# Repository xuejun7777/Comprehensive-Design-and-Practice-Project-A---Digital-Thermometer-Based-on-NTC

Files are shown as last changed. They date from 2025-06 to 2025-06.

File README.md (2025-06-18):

# NTC数字温度计综合设计项目

## 项目简介

基于STM32G030微控制器和NTC热敏电阻的数字温度计系统，包含完整的硬件设计、软件开发和PCB制作。

## 系统架构

### 硬件组成
- **MCU**: STM32G030 (ARM Cortex-M0+)
- **传感器**: NTC热敏电阻 (10kΩ@25°C, B=3950K)
- **显示**: 4位7段数码管
- **接口**: USB Type-C + UART

### 软件功能
- 12位ADC温度采集
- Steinhart-Hart方程温度转换
- 动态数码管显示
- 串口数据输出
- 开机学号显示

## 核心特性

- **通信**: 115200bps UART

## 项目结构

```
├── g030_adc_uart/          # 主程序代码
├── g030_display/           # 显示驱动
├── NTC/                    # 硬件设计V1
├── NTC2/                   # 硬件设计V2
├── final_submit/           # 最终提交文件
└── *.pdf                   # 实验报告文档
```

## 关键算法

### 温度转换公式
```c
// Steinhart-Hart方程
T = 1/((ln(Rt/R0)/B) + (1/T0)) - 273.15
```

### 自然对数实现
```c
// 泰勒级数展开避免math.h依赖
double tsp_ln(double a) {
    // 15阶泰勒级数计算
}
```

## 编译环境

- **IDE**: Keil MDK-ARM V5.39.0.0
- **编译器**: ArmClang V6.21
- **代码大小**: ~8KB Flash, ~2KB RAM

## 功能验证

✅ 温度测量精度  
✅ 数码管显示  
✅ 串口通信  
✅ 学号显示  
✅ 异常检测  
✅ PCB硬件  

## 应用场景

- 温度监测系统
- 实验室测温设备  
- 工业过程控制
- 教学实验平台

---

*本项目展示了完整的嵌入式系统开发流程，从硬件设计到软件实现的工程实践。*

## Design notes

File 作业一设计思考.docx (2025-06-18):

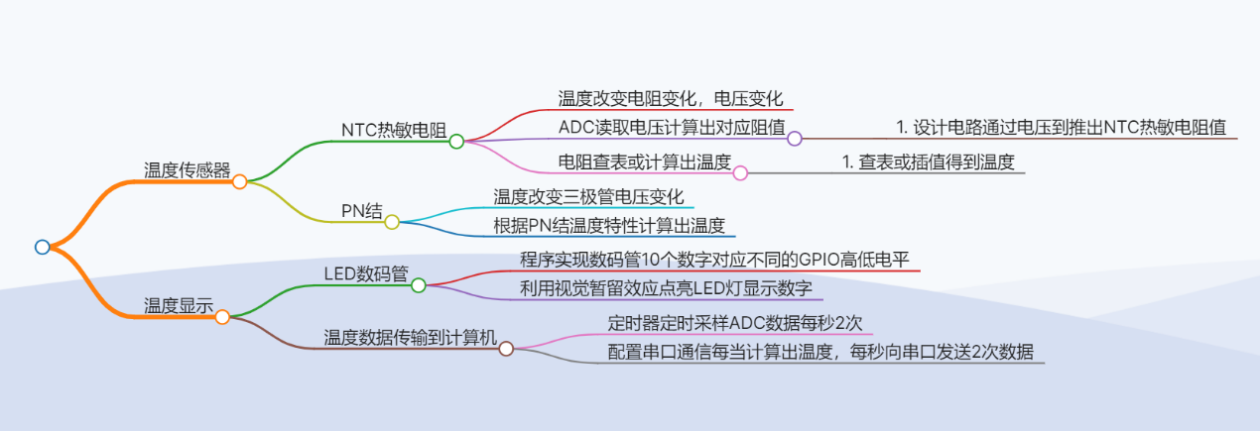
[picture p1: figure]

配置串口将温度通过串口传输到计算机

LED数码管显示

使用定时器定时每秒进行两次ADC的采样

单片机ADC采样的数字信号算出NTC电阻或PN结电压，计算出当前温度

NTC或PN结温度传感器，温度引起电阻或电压变化

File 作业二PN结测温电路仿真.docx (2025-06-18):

# 作业二PN结测温电路仿真

1、设计一个恒流源（可用器件：电阻、运放），可提供100uA恒定电流；

使用电阻和运算放大器的虚短虚断特性组成恒流源，简化示意图如下：

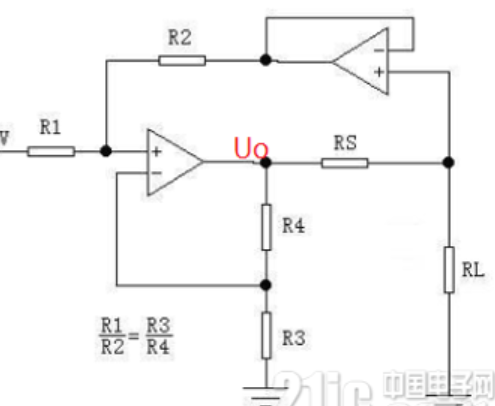
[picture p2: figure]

V*R2/R1=I*RS

单5V电源供电时，选择R1为10k Ω，R2为2k Ω，RS电阻值为10kΩ即可得到100uA恒定电流。

2、设计电路，减小反向比例电路中R1对测量精度的影响；

使用运算放大器组成电压缓冲器，由于虚断，反相输入端不会分流电流源的电流。

3、整个电路采用单5V电源供电；

使用到的所有运算放大器电源正端接5v电源，负端接地。

4、运放同相输入端的偏置电压以电阻网络的形式提供，请计算电阻阻值；

运放同相输入端需要偏置电压，使用两个电阻对5v电源分压，观察PN结温度特性可知需要偏置电压为588mv，计算出需用两个电阻（对应图中R5和R7）分别为11kΩ和1.6kΩ，即可将温度0~100℃对应到电压0.5v~3.5v。

5、运放增益、偏置如何调整？

调整运放的增益和偏置只需要调整相应的电阻网络，调整运放增益可以调节反相输入端所接电阻和反馈电阻（对应图中R10和R6）的阻值，或者接入可变电阻，调节可变电阻；调整偏置调整第4问中两个电阻（对应图中R5和R7）阻值或者接入可变电阻，调节可变电阻即可。

电路图如下：

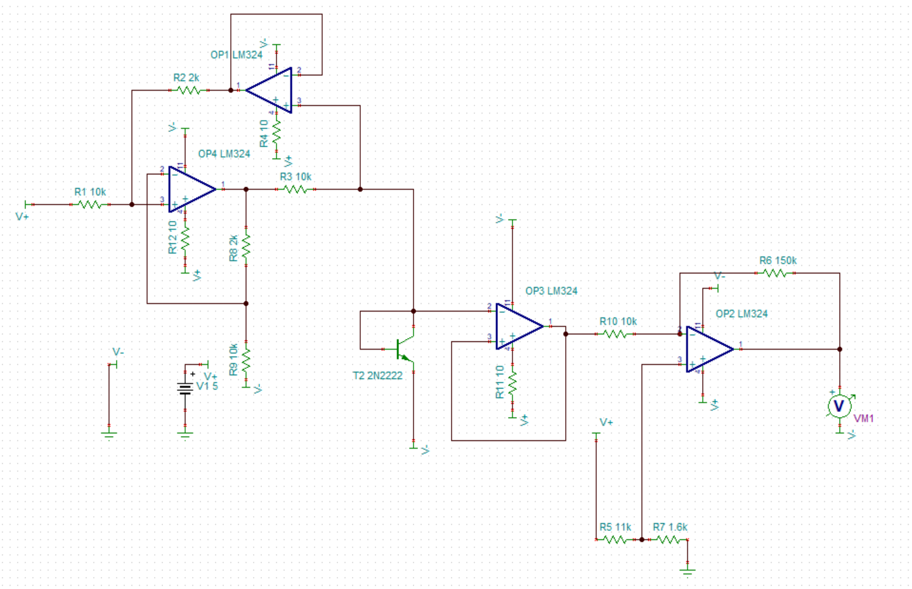
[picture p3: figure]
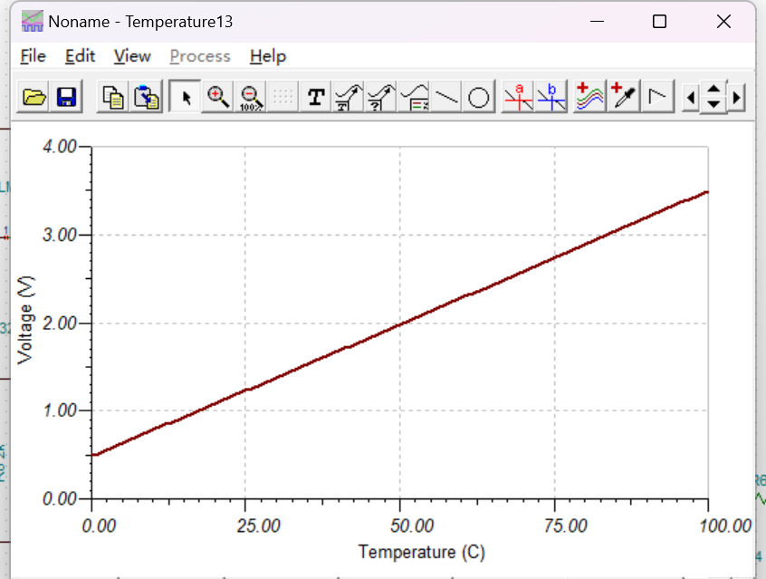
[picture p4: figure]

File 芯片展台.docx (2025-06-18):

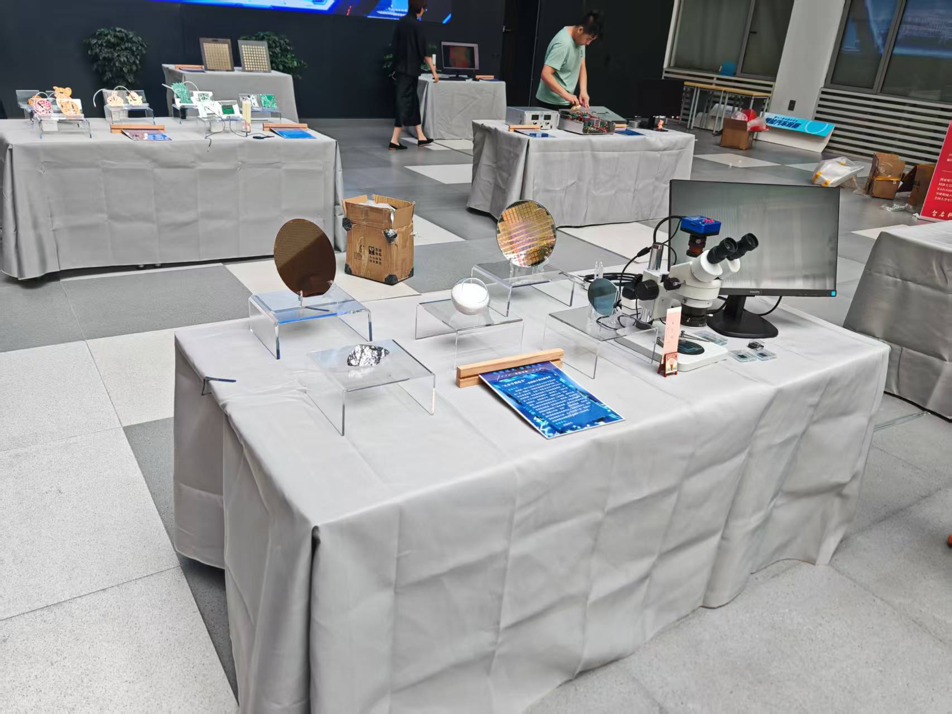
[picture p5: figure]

芯片展台

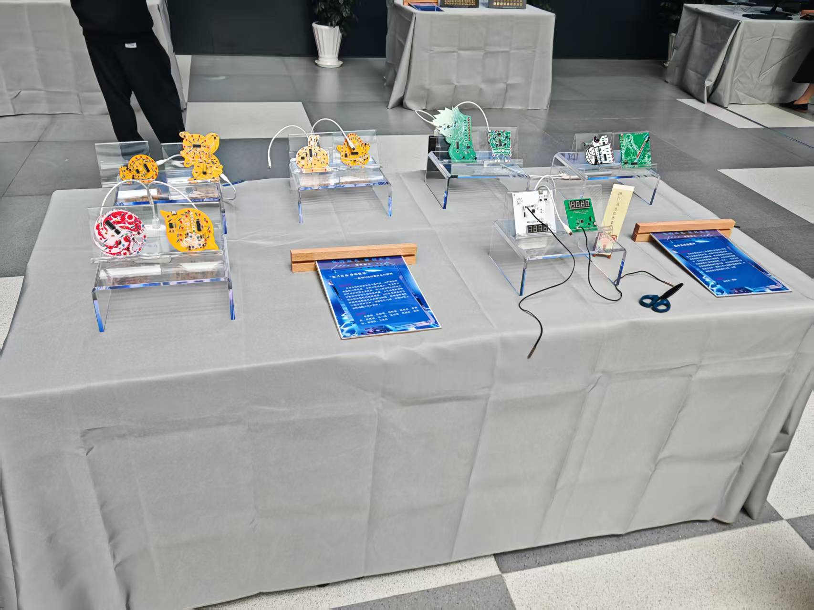
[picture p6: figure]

流水灯展台

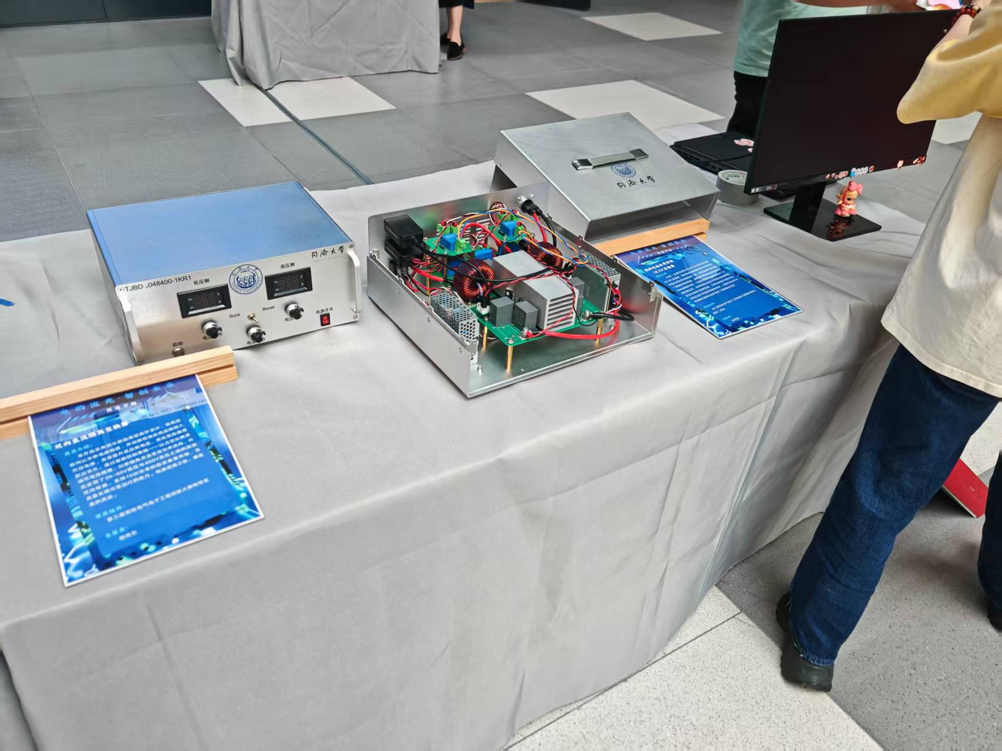
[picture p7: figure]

DC/DC变换器展台

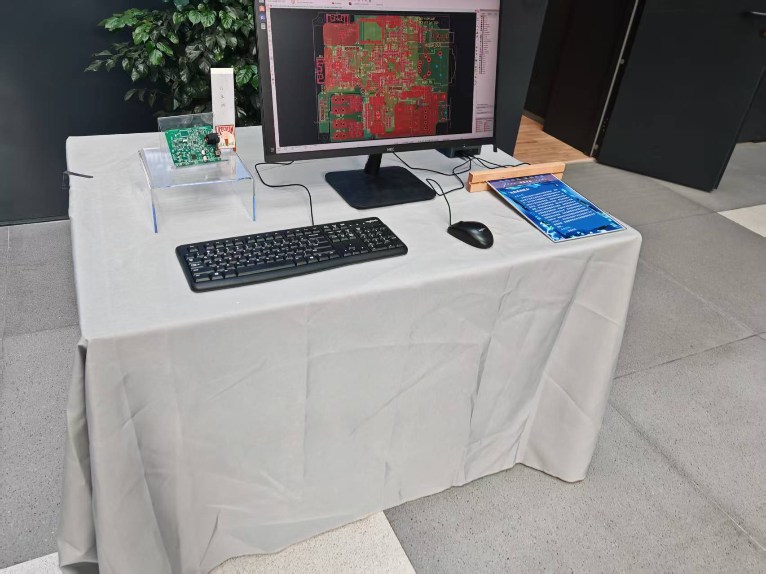
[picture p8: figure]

PCB电路板展台

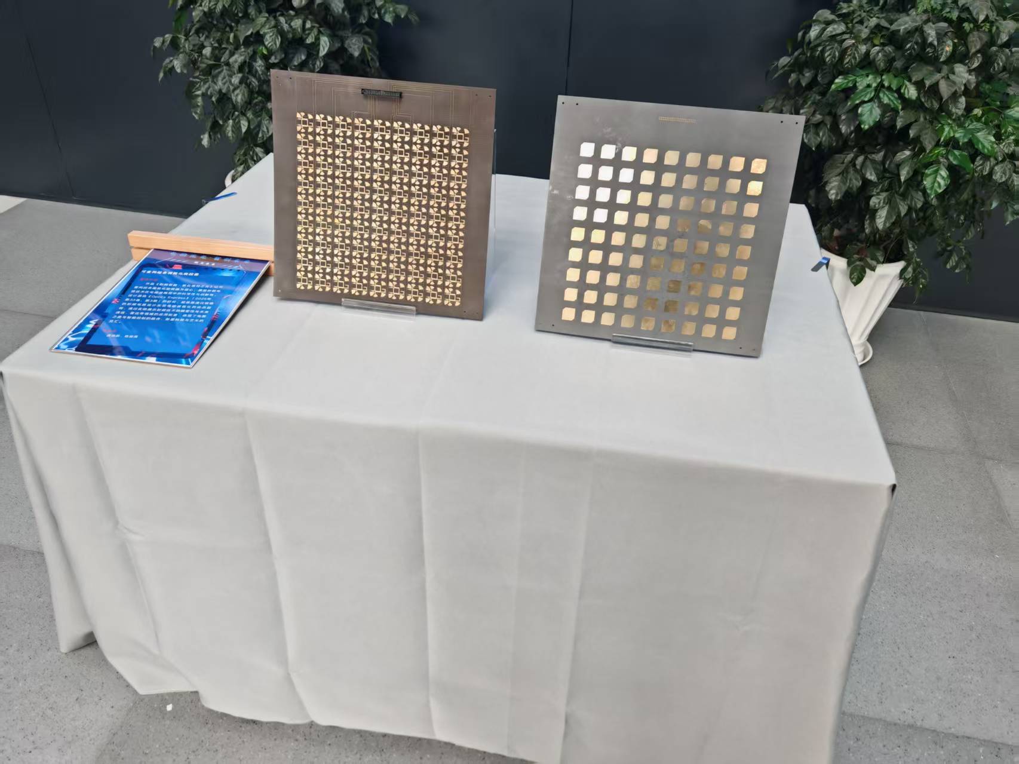
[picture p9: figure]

旋控器展台

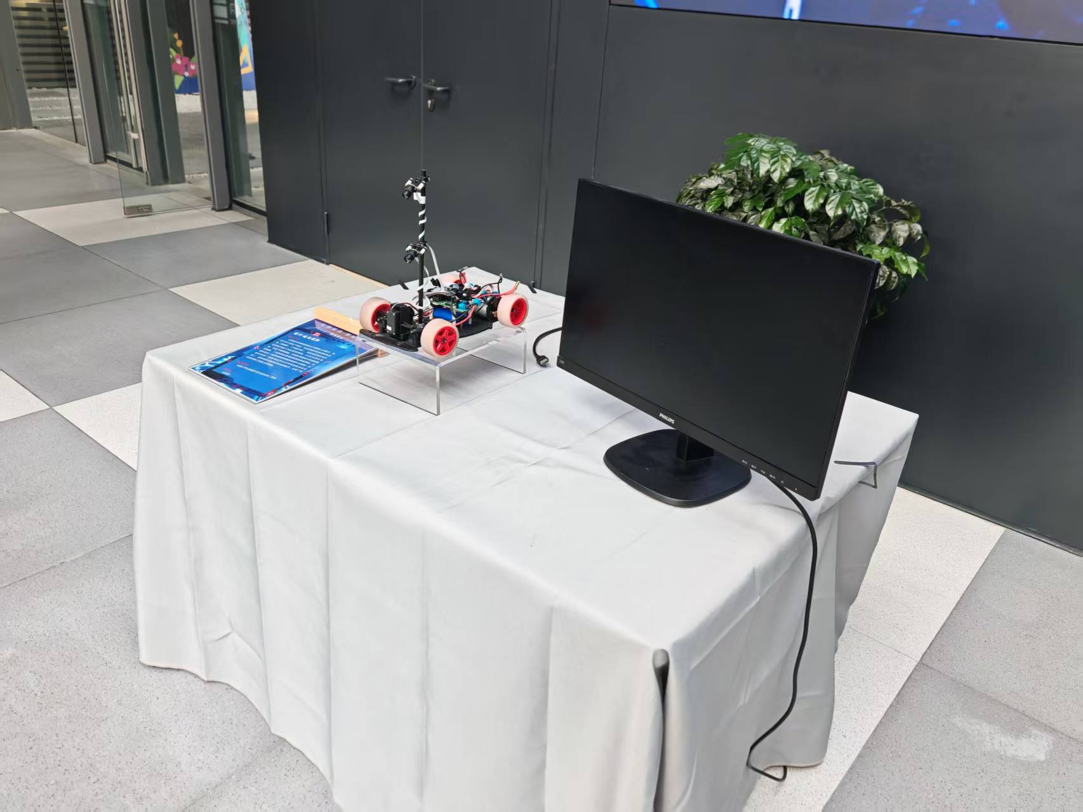
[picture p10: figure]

智能小车展台

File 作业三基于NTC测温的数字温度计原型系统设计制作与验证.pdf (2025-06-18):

## 基于 NTC 测温的数字温度计原型系统设计制作与验

## 证实验报告

引言

本实验的目的是设计一个使用 LED 数码管作为显示器件的数字温度计，通过测量 NTC 电阻 值来获取温度数据。实验中使用了 minisys G030 最小系统板，并通过 ADC 外设进行数据采 集，采集到的 NTC 热敏电阻的分压通过一系列换算得到温度数据并使用 LED 数码管显示。

## 电路设计

使用元器件 minisys G030、排针、排母、9013 三极管、数码管、330Ω、1KΩ、10KΩ 的电阻 等器件，根据要求，我们设计了以下电路：
1. NTC 电阻与一个 10KΩ 固定电阻构成 3.3V 的参考电压的分压网络，并使用单片机 ADC(PA0 管脚)测量中点电压；
2. 整个电路采用 minisys G030 最小系统板上提供的单 5V 电源供电；
3. 数码管八个笔端使用 minisys G030 上 PB0-7 串联 330Ω电阻直接驱动，4 个公共阴极使 用三极管扩流，并使用 minisys G030 上 PD0-3 驱动，三极管基极串一个 1kΩ电阻限流； 电路图如下：
图中的 STM32G030 及周边电路由 minisys G030 提供，原型电路需要连接 minisys、数码管 以及三极管、电阻等元器件。

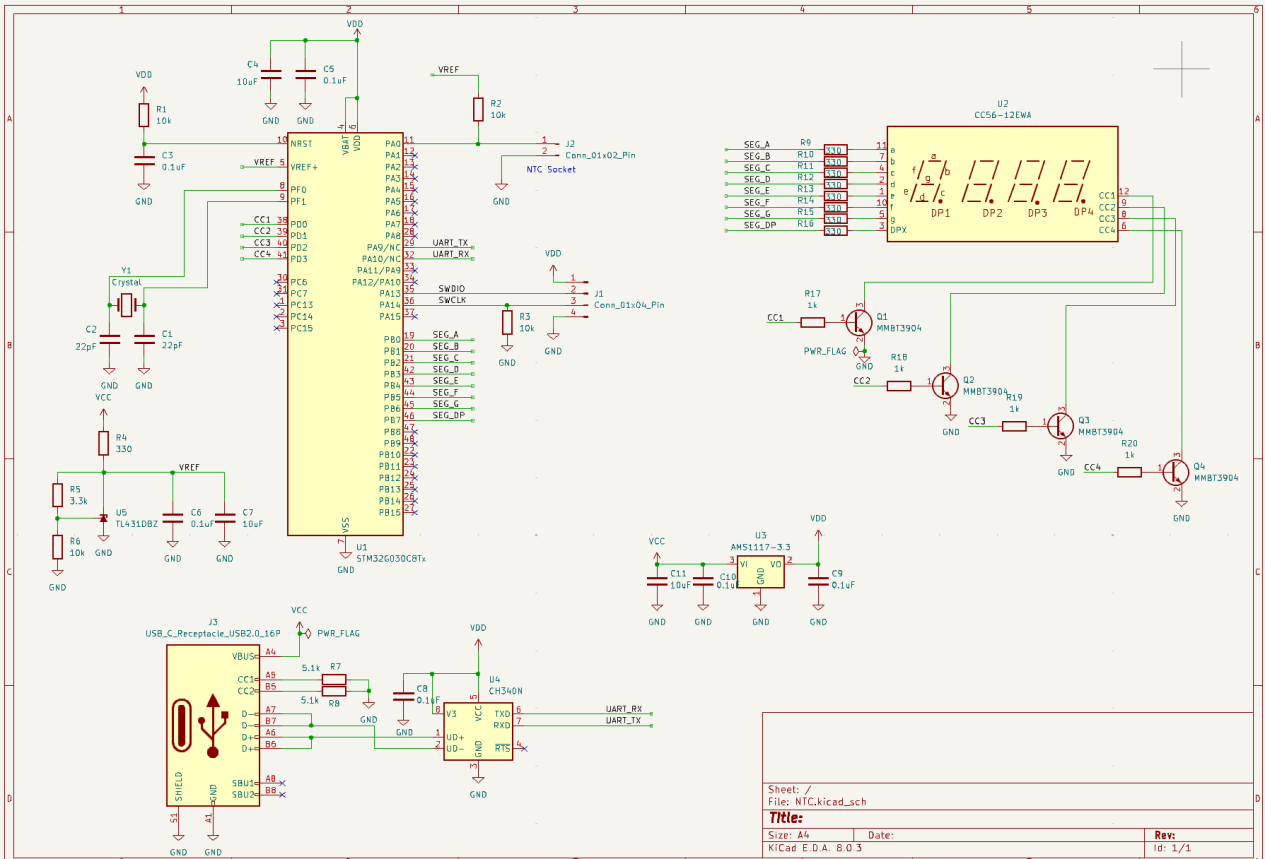
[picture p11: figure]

## 程序编写

根据要求编写单片机程序，实现了下功能：
1. LED 数码管动态扫描显示
按照时刻按照一定规则选择使能四个数码管的其中一个，数码管在 8 个笔端写入数字对 应的电平，下一个时刻使用另一个数码管并写入相应数字对应的电平即实现了动态扫描 显示数字，这样就可以尽可能少占用单片机管脚。
2. 每秒 2 次 ADC 数据采集
配置定时器 TIM3，要求 2Hz 频率采样 PA0 脚的电压，在 STM32CubeMX 中配置时钟树 64MHz，PSR 为 511，ARR 为 62499，并设置 ADC 采样转换的触发源是 TIM3 定时器溢 出就能实现每秒 2 次 ADC 数据采集。
3. 电阻值测量计算
NTC 热敏电阻与 10kΩ电阻对 3.3v 参考电压进行分压，根据 DC 采集的电压可以倒推出

NTC 电阻值，公式为R =

10000
3.3
v

-1

。

4. 根据 NTC 的温度-电阻函数，计算测得的温度数据，并显示在 LED 数码管上。
由于 STM32G030 不支持计算复杂运算，无法直接使用公式通过温度-电阻函数计算出温 度（不能进行对数计算），可以使用查表的方式根据表格中温度-电阻的对应关系，对于 表格中没有的阻值对应的温度可以将温度-阻值近似为线性函数进行线性插值（在实际 程序中直接定义使用 ADC-温度对应的表格数组进行一系列插值运算），得到温度值传给 处理数码管的函数，即可将温度显示在数码管上。

## 测试结果

实物图片：

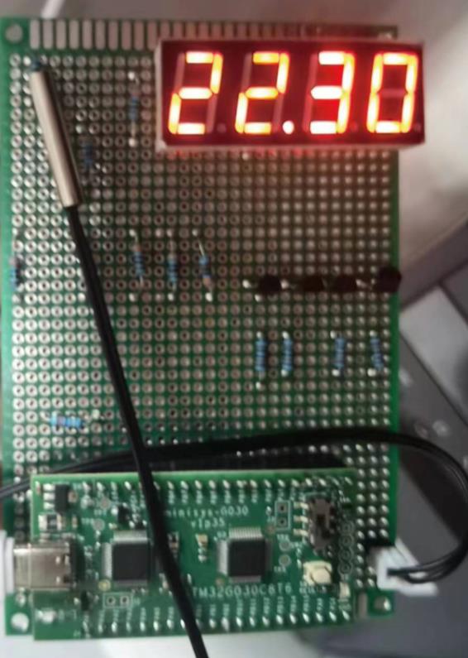
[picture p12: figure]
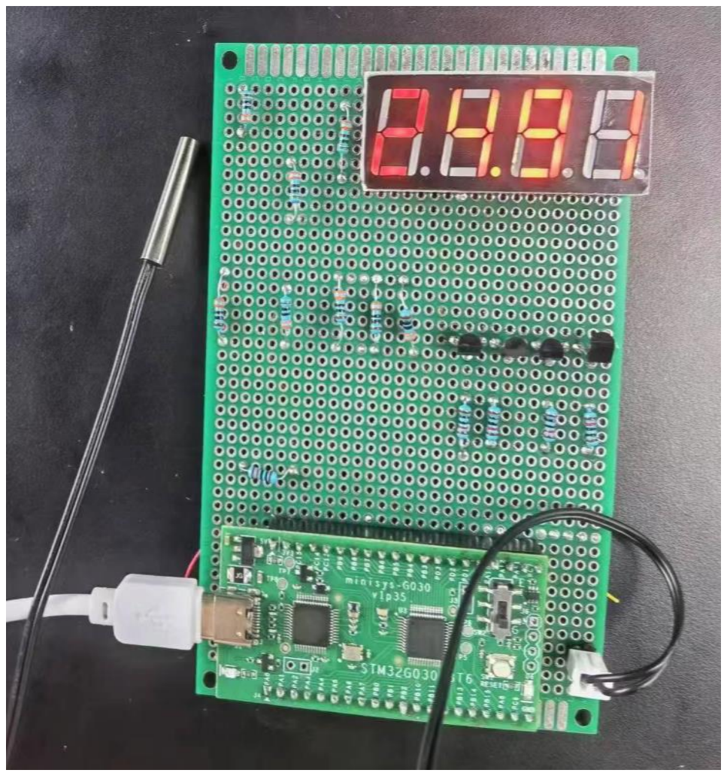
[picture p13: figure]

测试图片
图片展示升温过程：

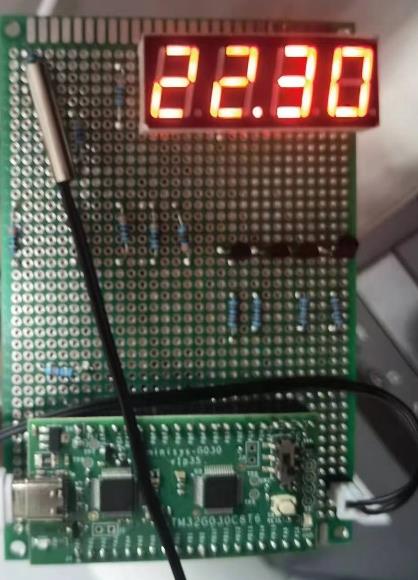
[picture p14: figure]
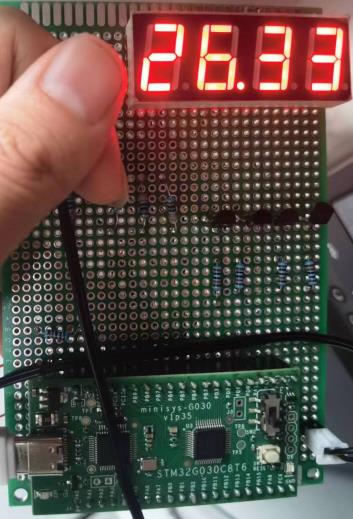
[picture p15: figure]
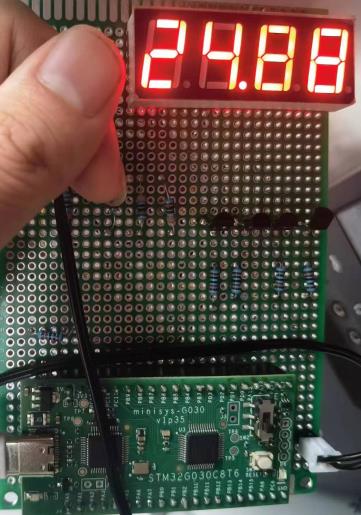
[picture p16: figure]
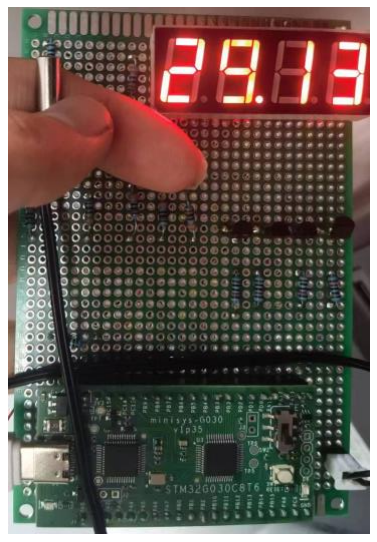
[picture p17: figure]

测试说明原型系统能够完成温度的计算然后用数码管显示温度数据，并且符合温度变化趋 势。
总结

通过本次实验，我们成功地设计并焊接了一个使用 LED 数码管作为显示器件的数字温度计 的原型系统。我们通过 ADC 采样分到的电压推算 NTC 电阻值和温度数据，并在 LED 数码管 上进行显示，设计并焊接的原型系统能够完成温度的计算，用数码管显示温度数据，并且符 合温度变化趋势。

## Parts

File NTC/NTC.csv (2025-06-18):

编号 | 位号 | 封装 | 数量 | 名称 | 供应商编号
1 | C6,C10,C9,C3,C8,C5 | C_0805_2012Metric_Pad1.18x1.45mm_HandSolder | 6 | 0.1uF
2 | R6,R1,R3,R2 | R_0805_2012Metric_Pad1.20x1.40mm_HandSolder | 4 | 10k
3 | C4,C11,C7 | C_0805_2012Metric_Pad1.18x1.45mm_HandSolder | 3 | 10uF
4 | J1 | PinHeader_1x04_P2.54mm_Vertical | 1 | Conn_01x04_Pin
5 | Q3,Q2,Q1,Q4 | SOT-23 | 4 | MMBT3904
6 | R15,R12,R9,R14,R13,R4,R16,R10,R11 | R_0805_2012Metric_Pad1.20x1.40mm_HandSolder | 9 | 330
7 | R17,R20,R18,R19 | R_0805_2012Metric_Pad1.20x1.40mm_HandSolder | 4 | 1k
8 | U2 | CA56-12EWA | 1 | CC56-12EWA
9 | R5 | R_0805_2012Metric_Pad1.20x1.40mm_HandSolder | 1 | 3.3k
10 | R7,R8 | R_0805_2012Metric_Pad1.20x1.40mm_HandSolder | 2 | 5.1k
11 | U4 | SOIC-8_3.9x4.9mm_P1.27mm | 1 | CH340N
12 | J3 | USB_C_Receptacle_HCTL_HC-TYPE-C-16P-01A | 1 | USB_C_Receptacle_USB2.0_16P
13 | U3 | SOT-223-3_TabPin2 | 1 | AMS1117-3.3
14 | C1,C2 | C_0805_2012Metric_Pad1.18x1.45mm_HandSolder | 2 | 22pF
15 | J2 | JST_XH_B2B-XH-A_1x02_P2.50mm_Vertical | 1 | Conn_01x02_Pin
16 | U1 | LQFP-48_7x7mm_P0.5mm | 1 | STM32G030C8Tx
17 | U5 | SOT-23 | 1 | TL431DBZ
18 | Y1 | Crystal_SMD_5032-2Pin_5.0x3.2mm | 1 | Crystal

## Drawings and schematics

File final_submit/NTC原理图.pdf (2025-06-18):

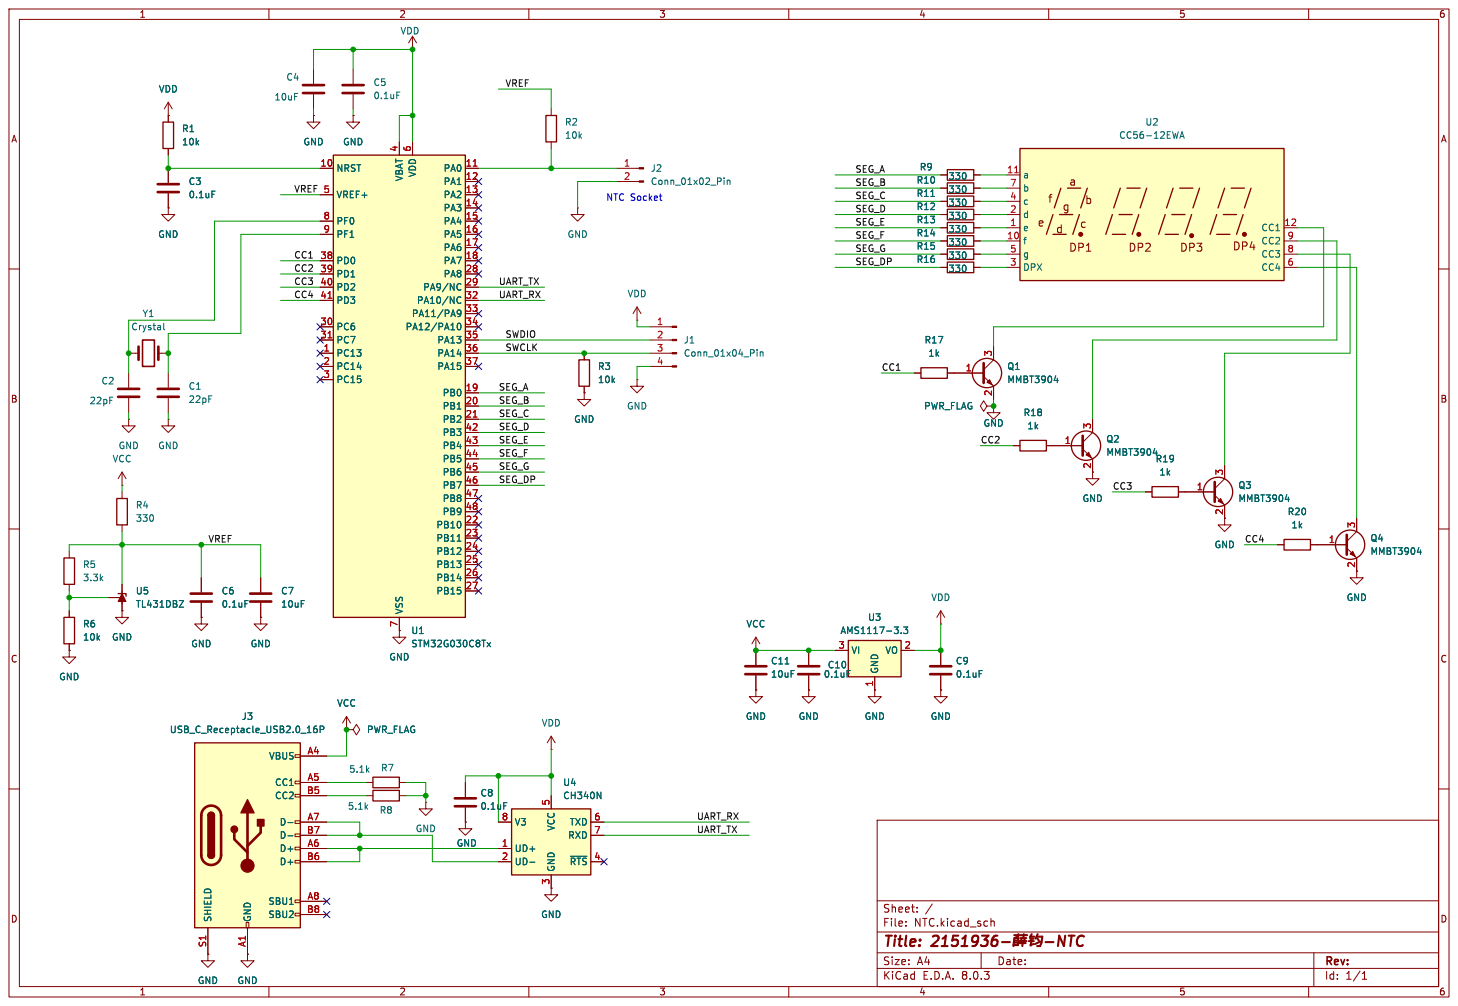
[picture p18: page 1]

File: NTC.kicad_sch Sheet: / GND

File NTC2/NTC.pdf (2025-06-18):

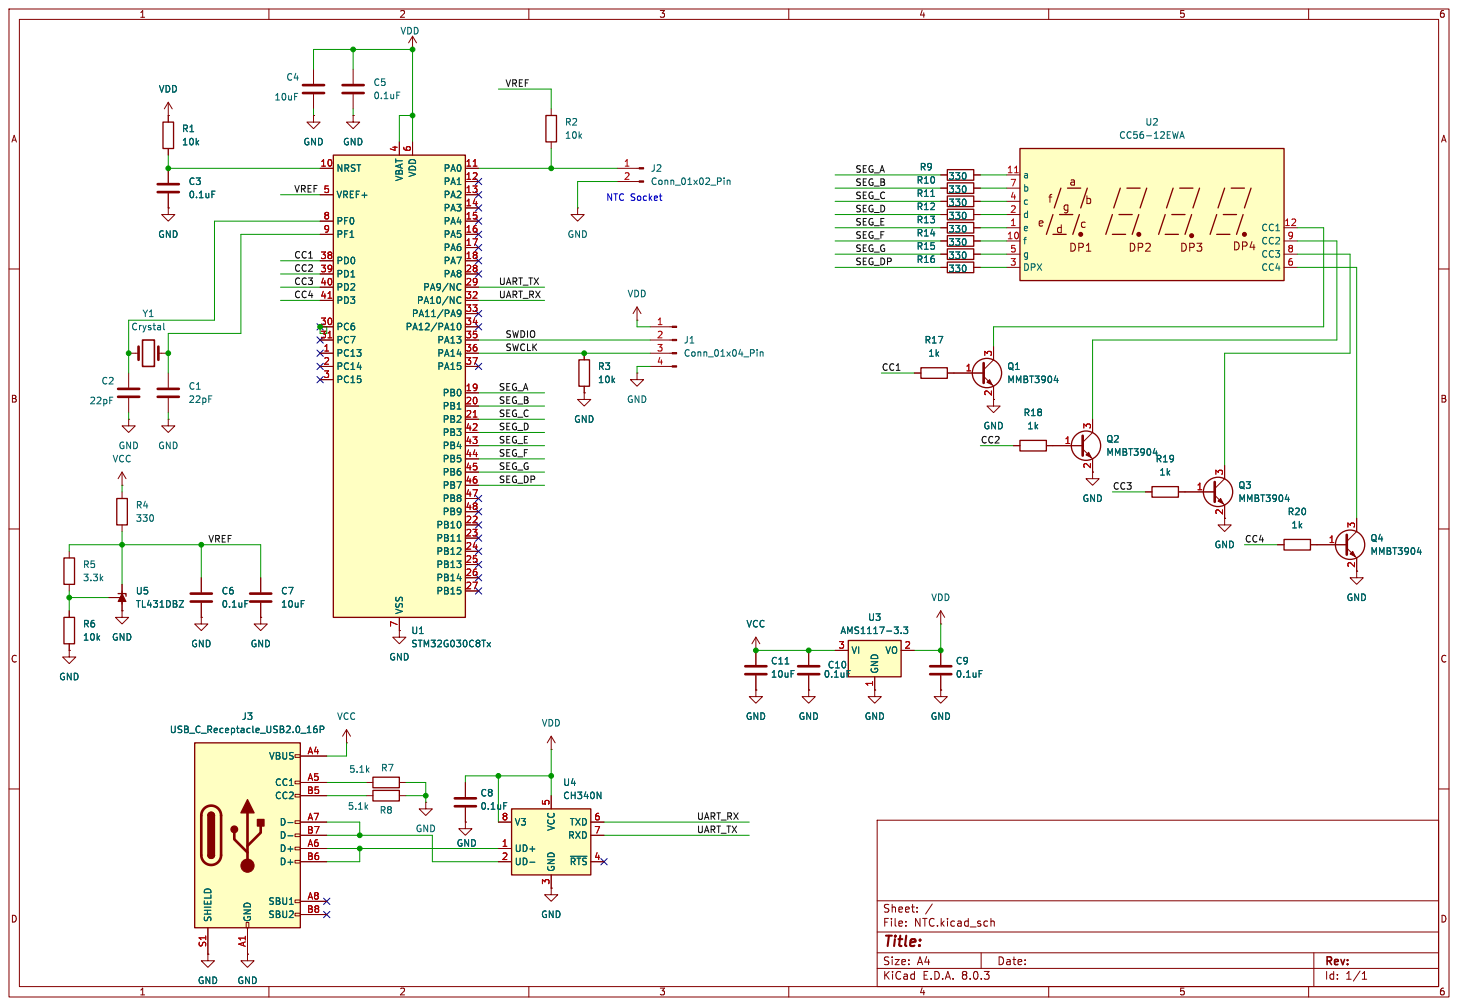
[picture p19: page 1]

2 3 Q3 GND MMBT3904 PC13 1 NRST 10 PA0 11 PA1 12 PA2 13 PA3 14 PA4 15 PA5 16 PA6 17 PA7 18 PB0 19 PC14 2 PB1 20 PB2 21 PB10 22 PB11 23 PB12 24 PB13 25 PB14 26 PB15 27 PA8 28 PA9/NC 29 PC15 3 PC6 30 PC7 31 PA10/NC 32 PA11/PA9 33 PA12/PA10 34 PA13 35 PA14 36 PA15 37 PD0 38 PD1 39 VBAT

Id: 1/1 Title: File: NTC.kicad_sch Sheet: /

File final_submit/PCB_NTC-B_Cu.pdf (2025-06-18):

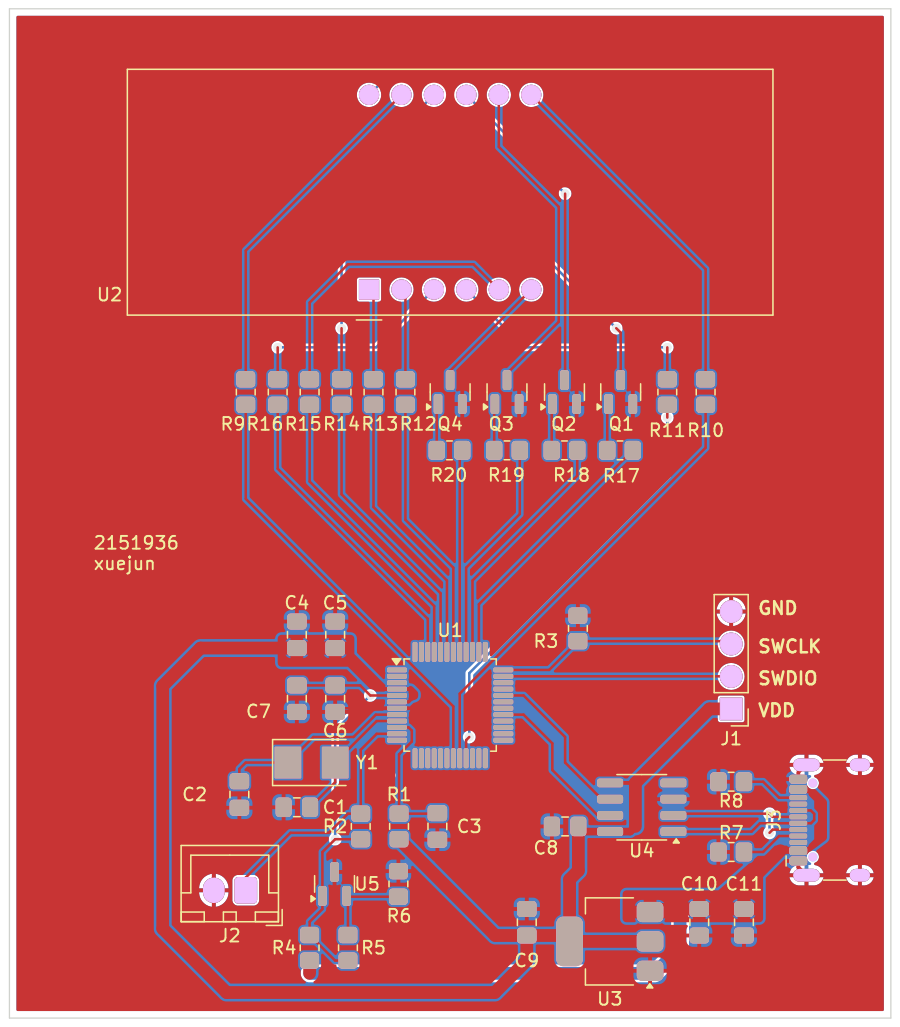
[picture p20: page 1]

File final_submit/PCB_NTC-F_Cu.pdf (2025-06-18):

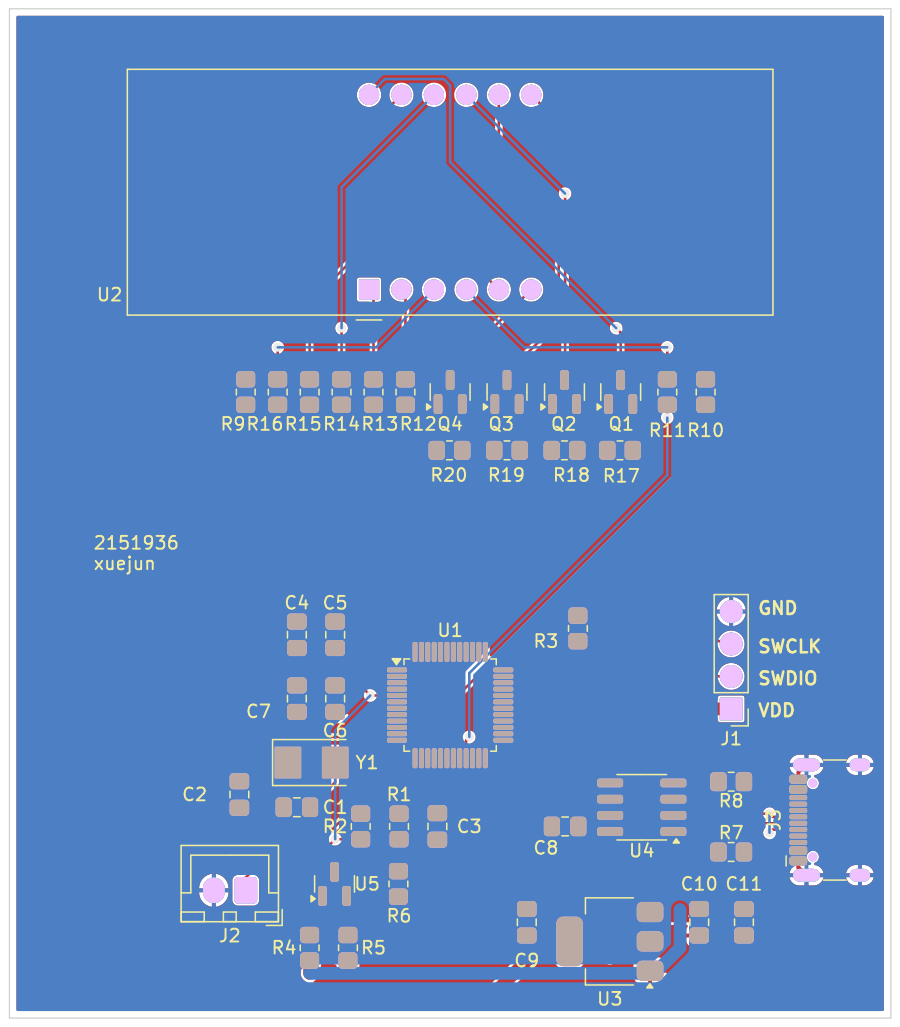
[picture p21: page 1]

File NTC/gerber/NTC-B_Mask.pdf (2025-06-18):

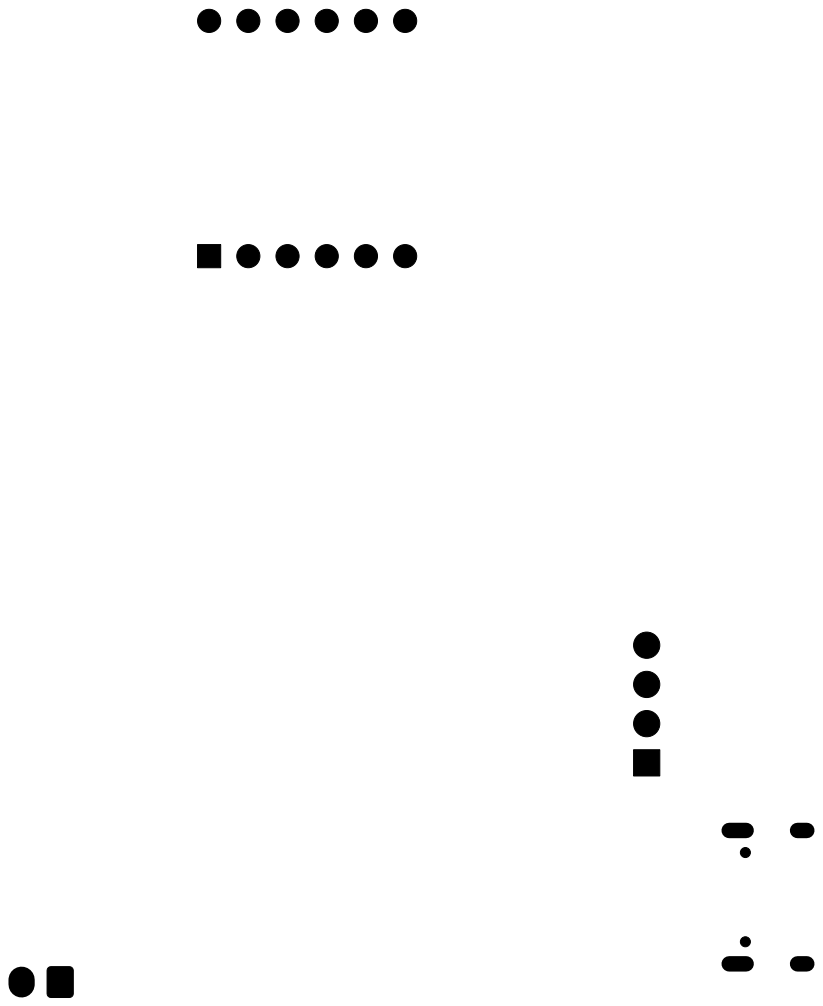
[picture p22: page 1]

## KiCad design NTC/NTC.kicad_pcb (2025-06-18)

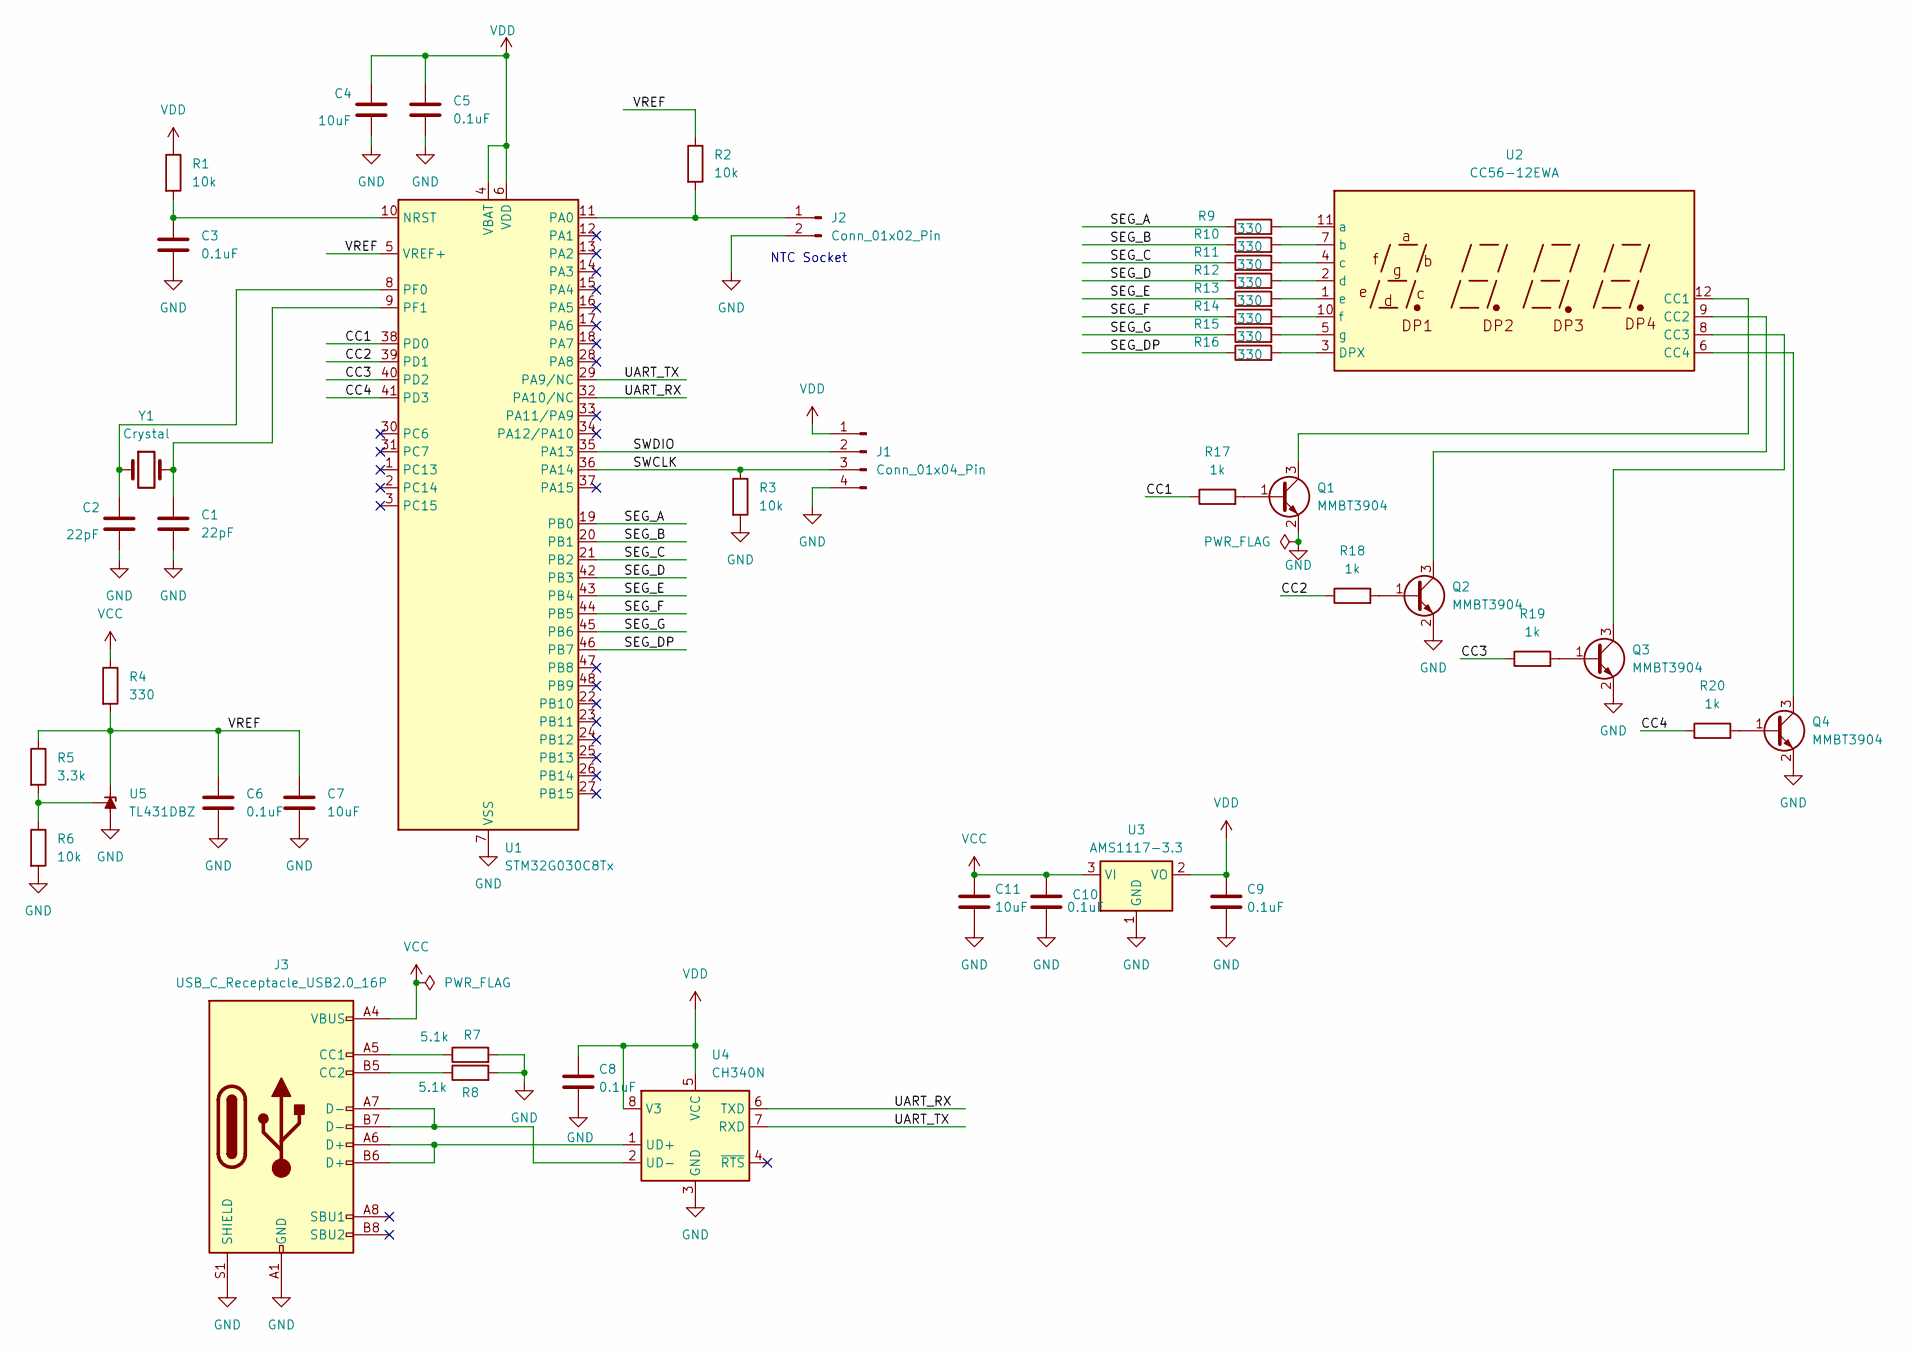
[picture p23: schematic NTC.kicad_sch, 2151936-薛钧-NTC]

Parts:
C1, C2: 22pF; C_0805_2012Metric_Pad1.18x1.45mm_HandSolder
C3, C5, C6, C8, C9, C10: 0.1uF; C_0805_2012Metric_Pad1.18x1.45mm_HandSolder
C4, C7, C11: 10uF; C_0805_2012Metric_Pad1.18x1.45mm_HandSolder
J1: Conn_01x04_Pin; PinHeader_1x04_P2.54mm_Vertical
J2: Conn_01x02_Pin; JST_XH_B2B-XH-A_1x02_P2.50mm_Vertical
J3: USB_C_Receptacle_USB2.0_16P; USB_C_Receptacle_HCTL_HC-TYPE-C-16P-01A
Q1, Q2, Q3, Q4: MMBT3904; SOT-23
R1, R2, R3, R6: 10k; R_0805_2012Metric_Pad1.20x1.40mm_HandSolder
R4, R9, R10, R11, R12, R13, R14, R15, R16: 330; R_0805_2012Metric_Pad1.20x1.40mm_HandSolder
R5: 3.3k; R_0805_2012Metric_Pad1.20x1.40mm_HandSolder
R7, R8: 5.1k; R_0805_2012Metric_Pad1.20x1.40mm_HandSolder
R17, R18, R19, R20: 1k; R_0805_2012Metric_Pad1.20x1.40mm_HandSolder
U1: STM32G030C8Tx; LQFP-48_7x7mm_P0.5mm
U2: CC56-12EWA; CA56-12EWA
U3: AMS1117-3.3; SOT-223-3_TabPin2
U4: CH340N; SOIC-8_3.9x4.9mm_P1.27mm
U5: TL431DBZ; SOT-23
Y1: Crystal; Crystal_SMD_5032-2Pin_5.0x3.2mm

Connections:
/CC1: R17.1, U1.38 (PD0)
/CC2: R18.1, U1.39 (PD1)
/CC3: R19.1, U1.40 (PD2)
/CC4: R20.1, U1.41 (PD3)
/SEG_A: R9.1, U1.19 (PB0)
/SEG_B: R10.1, U1.20 (PB1)
/SEG_C: R11.1, U1.21 (PB2)
/SEG_D: R12.1, U1.42 (PB3)
/SEG_DP: R16.1, U1.46 (PB7)
/SEG_E: R13.1, U1.43 (PB4)
/SEG_F: R14.1, U1.44 (PB5)
/SEG_G: R15.1, U1.45 (PB6)
/SWCLK: J1.3, R3.1, U1.36 (PA14)
/SWDIO: J1.2, U1.35 (PA13)
/UART_RX: U1.32 (PA10/NC), U4.6 (TXD)
/UART_TX: U1.29 (PA9/NC), U4.7 (RXD)
/VREF: C6.1, C7.1, R2.1, R4.2, R5.1, U1.5 (VREF+), U5.1 (K)
GND: C1.2, C2.2, C3.2, C4.2, C5.2, C6.2, C7.2, C8.2, C9.2, C10.2, C11.2, J1.4, J2.2, J3.A1 (GND), J3.A12 (GND), J3.B1 (GND), J3.B12 (GND), J3.S1 (SHIELD), Q1.2 (E), Q2.2 (E), Q3.2 (E), Q4.2 (E), R3.2, R6.2, R7.2, R8.2, U1.7 (VSS), U3.1 (GND), U4.3 (GND), U5.3 (A)
unnamed: J2.1, R2.2, U1.11 (PA0)
unnamed: J3.A5 (CC1), R7.1
unnamed: J3.B5 (CC2), R8.1
unnamed: Q1.1 (B), R17.2
unnamed: Q1.3 (C), U2.12 (CC1)
unnamed: Q2.1 (B), R18.2
unnamed: Q2.3 (C), U2.9 (CC2)
unnamed: Q3.1 (B), R19.2
unnamed: Q3.3 (C), U2.8 (CC3)
unnamed: Q4.1 (B), R20.2
unnamed: Q4.3 (C), U2.6 (CC4)
unnamed: C3.1, R1.2, U1.10 (NRST)
unnamed: C2.1, U1.8 (PF0), Y1.1
unnamed: C1.1, U1.9 (PF1), Y1.2
unnamed: R16.2, U2.3 (DPX)
unnamed: R9.2, U2.11 (a)
unnamed: R10.2, U2.7 (b)
unnamed: R11.2, U2.4 (c)
unnamed: R12.2, U2.2 (d)
unnamed: R13.2, U2.1 (e)
unnamed: R14.2, U2.10 (f)
unnamed: R15.2, U2.5 (g)
unnamed: J3.A6 (D+), J3.B6 (D+), U4.1 (UD+)
unnamed: J3.A7 (D-), J3.B7 (D-), U4.2 (UD-)
unnamed: R5.2, R6.1, U5.2 (REF)
VCC: C10.1, C11.1, J3.A4 (VBUS), J3.A9 (VBUS), J3.B4 (VBUS), J3.B9 (VBUS), R4.1, U3.3 (VI)
VDD: C4.1, C5.1, C8.1, C9.1, J1.1, R1.1, U1.4 (VBAT), U1.6 (VDD), U3.2 (VO), U4.5 (VCC), U4.8 (V3)

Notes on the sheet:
NTC Socket

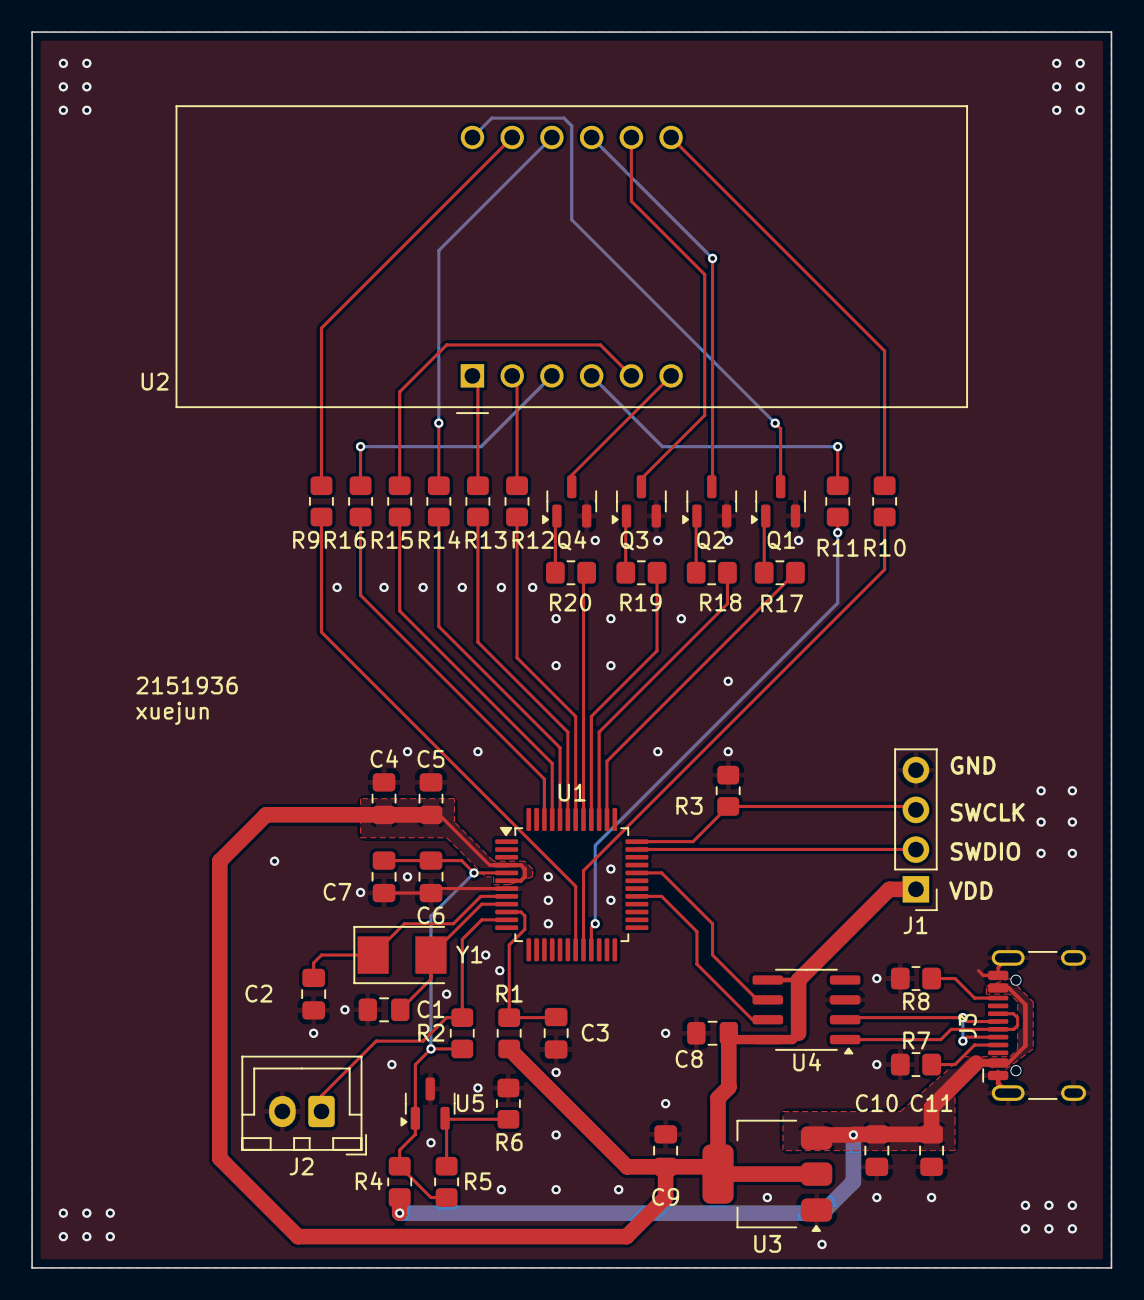
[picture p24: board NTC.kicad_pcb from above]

Board: 2 copper layers, 69.0 x 79.0 mm, 44 parts (0 on the bottom side), 45 nets.

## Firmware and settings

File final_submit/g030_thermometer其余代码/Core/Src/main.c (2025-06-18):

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
/* Includes ------------------------------------------------------------------*/
#include "main.h"
#include "adc.h"
#include "tim.h"
#include "usart.h"
#include "gpio.h"

/* USER CODE BEGIN Includes */
#include <stdio.h>
#include "string.h"
#include <math.h>
/* USER CODE END Includes */

/* USER CODE BEGIN PD */
#define TSP_SHORT_CIRCUIT_THRESHOLD 	20U			/*!<NTC short-circuit */
#define TSP_OPEN_CIRCUIT_THRESHOLD 		4090U		/*!<NTC open-circuit */
#define LED_SEG_REFRESH_PERIOD		5
#define TSP_NTC_B_VALUE   			3950U 			/*!<NTC B value */
#define TSP_NTC_RATED_TEMP          25U   			/*!<NTC rated temperature(25¡æ) */
#define TSP_NTC_RATED_RES           10000.0F 		/*!<NTC rated resistance 10K*/
#define TSP_NTC_KELVIN_VALUE		273.15F			/*!<NTC kelvin value */
#define TSP_NTC_T2_VALUE			TSP_NTC_KELVIN_VALUE + TSP_NTC_RATED_TEMP
#define TSP_NTC_ERROR_VALUE			0.5F 			/*!<NTC error,log replace of ln, need to add the error */
#define TSP_ADC_FULL_SCALE 		    4095.0F	        /*!<ADC scale*/
#define TSP_ADC_VOLTAGE_REF 	    3.28F	        /*!<Voltage reference*/
/* USER CODE END PD */


/* USER CODE BEGIN PV */
uint8_t adc_convert_cplt;
uint32_t stuid_cplt = 0;
float volt;
float resistant;
float tc;
float tc2;
/* USER CODE END PV */

void SystemClock_Config(void);
/* USER CODE BEGIN PFP */
uint8_t ch;
uint8_t ch_r;
__IO uint8_t dig_array[4]={0x01, 0x05, 0x01, 0x02};
extern void select_digit(uint8_t dig);
extern void write_segment(uint8_t seg);
extern void DisplayDigitFLOAT(uint32_t num);
extern void DisplayCallback(void);
static float tsp_ResistanceToTemperature( uint16_t adc_val );

const uint8_t seg_table[16] = {
	0x3f,		//"0"
	0x06,		//"1"
	0x5b,		//"2"
	0x4f,		//"3"
	0x66,		//"4"
	0x6d,		//"5"
	0x7d,		//"6"
	0x07,		//"7"
	0x7f,		//"8"
	0x6f,		//"9"
	0x77,		//"A"
	0x7c,		//"b"
	0x39,		//"C"
	0x5e,		//"d"
	0x79,		//"E"
	0x71		//"F"
};

//2151936
const uint32_t StuID[5] = {
	2151, 1519,5193,1936, 9360
};
static const uint16_t NTC_adc_table[] = 
{
	3996, 3988, 3981, 3972, 3964, 3955, 3945, 3935, 3924, 3912, 	
	3900, 3887, 3874, 3860, 3845, 3830, 3813, 3796, 3778, 3760, 	
	3740, 3720, 3698, 3676, 3653, 3629, 3604, 3578, 3551, 3524, 	
	3495, 3465, 3435, 3403, 3371, 3337, 3303, 3267, 3231, 3194, 	
	3156, 3118, 3078, 3038, 2997, 2955, 2913, 2870, 2826, 2782, 	
	2738, 2693, 2648, 2602, 2556, 2510, 2464, 2417, 2371, 2324, 	
	2278, 2231, 2185, 2139, 2093, 2048, 2002, 1957, 1913, 1868, 	
	1825, 1781, 1739, 1697, 1655, 1614, 1574, 1534, 1495, 1456, 	
	1419, 1382, 1346, 1310, 1275, 1241, 1208, 1175, 1143, 1112, 	
	1081, 1052, 1023, 994, 967, 940, 914, 888, 863, 839, 	
	815, 792, 770, 748, 727, 707, 687, 668, 649, 631, 	
	613, 596, 579, 563, 547, 532, 517, 502, 488, 475, 	
	462, 449, 436, 424, 413, 401, 390, 380, 369, 359, 	
	350, 340, 331, 322, 314, 305, 297, 289, 282, 274, 	
	267, 260, 253, 247, 240, 234, 228, 222, 217, 211, 	
	206, 201, 196, 191, 186, 181, 177, 173, 168, 164, 	
	160
};

static const uint16_t NTC_temperature_table[] = 
{
	-40, -39, -38, -37, -36, -35, -34, -33, -32, -31, 	
	-30, -29, -28, -27, -26, -25, -24, -23, -22, -21, 	
	-20, -19, -18, -17, -16, -15, -14, -13, -12, -11, 	
	-10, -9, -8, -7, -6, -5, -4, -3, -2, -1, 	
	0, 1, 2, 3, 4, 5, 6, 7, 8, 9, 	
	10, 11, 12, 13, 14, 15, 16, 17, 18, 19, 	
	20, 21, 22, 23, 24, 25, 26, 27, 28, 29, 	
	30, 31, 32, 33, 34, 35, 36, 37, 38, 39, 	
	40, 41, 42, 43, 44, 45, 46, 47, 48, 49, 	
	50, 51, 52, 53, 54, 55, 56, 57, 58, 59, 	
	60, 61, 62, 63, 64, 65, 66, 67, 68, 69, 	
	70, 71, 72, 73, 74, 75, 76, 77, 78, 79, 	
	80, 81, 82, 83, 84, 85, 86, 87, 88, 89, 	
	90, 91, 92, 93, 94, 95, 96, 97, 98, 99, 	
	100, 101, 102, 103, 104, 105, 106, 107, 108, 109, 	
	110, 111, 112, 113, 114, 115, 116, 117, 118, 119, 	
	120
};

/* USER CODE END PFP */

/* USER CODE BEGIN 0 */
double tsp_ln(double a)
{
	int N = 15;
	int k , nk;
	double x, xx , y;
	x = ( a - 1 ) / ( a + 1 );
	xx = x * x;
	nk = 2 * N + 1;
	y = 1.0 / nk;
	for( k = N; k > 0; k-- )
	{
		nk = nk - 2;
		y = ( 1.0 / nk ) + ( xx * y );
	}

	return ( 2.0 * x * y );
}
void DisplayCallback(void)
{
	uint8_t dig;
	uint32_t tick = HAL_GetTick();

	if((tick%LED_SEG_REFRESH_PERIOD) == 0)
	{
		dig = (tick/LED_SEG_REFRESH_PERIOD)%4;
		select_digit(dig);

		if(stuid_cplt <10 && stuid_cplt % 5 == 4 && dig == 3)		//digit is off
		{
			write_segment(0x00);			
		}
		else if((dig_array[dig]&0x80) != 0)		//display minus
		{
			write_segment(0x40);	
		}
		else if(dig == 1 && stuid_cplt > 9)		//add dot
		{
			write_segment(seg_table[dig_array[3-dig]&0x0f] | 0x80);
		}
		else
		{
			write_segment(seg_table[dig_array[3-dig]&0x0f]);
		}

	}
}


void select_digit(uint8_t dig)
{
	switch(dig)
	{
		case 0:
			HAL_GPIO_WritePin(GPIOD, LED_CC0_Pin, GPIO_PIN_SET);
			HAL_GPIO_WritePin(GPIOD, LED_CC1_Pin, GPIO_PIN_RESET);
			HAL_GPIO_WritePin(GPIOD, LED_CC2_Pin, GPIO_PIN_RESET);
			HAL_GPIO_WritePin(GPIOD, LED_CC3_Pin, GPIO_PIN_RESET);
			break;
		case 1:
			HAL_GPIO_WritePin(GPIOD, LED_CC0_Pin, GPIO_PIN_RESET);
			HAL_GPIO_WritePin(GPIOD, LED_CC1_Pin, GPIO_PIN_SET);
			HAL_GPIO_WritePin(GPIOD, LED_CC2_Pin, GPIO_PIN_RESET);
			HAL_GPIO_WritePin(GPIOD, LED_CC3_Pin, GPIO_PIN_RESET);
			break;
		case 2:
			HAL_GPIO_WritePin(GPIOD, LED_CC0_Pin, GPIO_PIN_RESET);
			HAL_GPIO_WritePin(GPIOD, LED_CC1_Pin, GPIO_PIN_RESET);
			HAL_GPIO_WritePin(GPIOD, LED_CC2_Pin, GPIO_PIN_SET);
			HAL_GPIO_WritePin(GPIOD, LED_CC3_Pin, GPIO_PIN_RESET);
			break;
		case 3:
			HAL_GPIO_WritePin(GPIOD, LED_CC0_Pin, GPIO_PIN_RESET);
			HAL_GPIO_WritePin(GPIOD, LED_CC1_Pin, GPIO_PIN_RESET);
			HAL_GPIO_WritePin(GPIOD, LED_CC2_Pin, GPIO_PIN_RESET);
			HAL_GPIO_WritePin(GPIOD, LED_CC3_Pin, GPIO_PIN_SET);
			break;
		default:
			break;
	}
}


void write_segment(uint8_t seg)
{
	HAL_GPIO_WritePin(GPIOB, seg, GPIO_PIN_SET);
	HAL_GPIO_WritePin(GPIOB, ~seg, GPIO_PIN_RESET);
}



void DisplayDigitFLOAT(uint32_t num)
{
	uint32_t tmp;
	if(num > 9999)
	{
		for(uint8_t i=0;i<8;i++)
			dig_array[i] = 0x0f;
	}
	else
	{
		tmp = num;
		for(uint8_t i=0;i<4;i++)
		{
			if((tmp == 0)&&(i!=0))
			{
				dig_array[i] = 0xff;
			}
			else
			{
				dig_array[i] = tmp%10;			
			}
			tmp = tmp/10;
		}
			
	}
}


static float tsp_BinaryTableSearch( uint16_t adc_val )
{
	uint16_t start = 0U, end = 0U, mid = 0U;

	/* Get the arry length */
	end = ( sizeof( NTC_adc_table )/ sizeof( NTC_adc_table[0] ) ) - 1U;

	/* Data anomaly judgment */
	if( adc_val <= TSP_SHORT_CIRCUIT_THRESHOLD )
	{
		return 1.0F;
	}
	else if( adc_val >= TSP_OPEN_CIRCUIT_THRESHOLD )
	{
		return 2.0F;
	}
	else if( adc_val > NTC_adc_table[0] )
	{
		return 3.0F;
	}
	else if( adc_val < NTC_adc_table[end - 1U] )
	{
		return 4.0F;
	}
	else
	{
		/* MISRA-C coding rules */
	}

	while ( start <= end )
	{
		/* Get the mid value */
		mid = (start + end) >> 1; 

		/* Just find */
		if( adc_val ==  NTC_adc_table[mid] )
		{
			break;
		}
		/* Right in between two temperature points */
		if( ( adc_val < NTC_adc_table[mid] ) && ( adc_val > NTC_adc_table[mid+1U] ) )
		{
			break;
		}

		/* The current AD value less than the middle of the array indicates 
		 * the second half of the number to look for 
		 */
		if( adc_val < NTC_adc_table[mid] )
		{
			start = mid + 1U; 
		}
		/* The current AD value greater than the middle of the array indicates 
		 * that the number to be found is in the first half 
		 */
		else if( adc_val > NTC_adc_table[mid] )
		{
			end = mid - 1U;
		}
		else
		{
			/* MISRA-C coding rules */
		}
	}

 	return ( NTC_temperature_table[mid] + (float)( NTC_adc_table[mid] - adc_val ) * (float)( NTC_temperature_table[mid+1] - NTC_temperature_table[mid] ) / (float)( NTC_adc_table[mid]-NTC_adc_table[mid+1] ) );
	
	// return (mid-40) +  (float)(NTC_adc_table[mid] -key)/(float)(NTC_adc_table[mid]-NTC_adc_table[mid+1]);
}


void HAL_ADC_ConvCpltCallback(ADC_HandleTypeDef* hadc)
{
	uint16_t value;
	if(HAL_IS_BIT_SET(HAL_ADC_GetState(&hadc1), HAL_ADC_STATE_REG_EOC))
	{
		value = HAL_ADC_GetValue(&hadc1);
		//volt = value *3.3/4096;
		//resistant = 10000 / (3.3 / volt - 1);
		//tc = tsp_BinaryTableSearch(value);
		tc = tsp_ResistanceToTemperature(value);
		if (++stuid_cplt > 9) {
			adc_convert_cplt = 1;
		}
		else {
			int i = stuid_cplt % 5;
			DisplayDigitFLOAT(StuID[i]);
		}
	}
}

/* USER CODE END 0 */

/**
  * @brief  The application entry point.
  * @retval int
  */
int main(void)
{
  /* USER CODE BEGIN 1 */
	char txbuf[32];
	int len;
  /* USER CODE END 1 */

  /* MCU Configuration--------------------------------------------------------*/

  /* Reset of all peripherals, Initializes the Flash interface and the Systick. */
  HAL_Init();

  /* Configure the system clock */
  SystemClock_Config();

  /* Initialize all configured peripherals */
  MX_GPIO_Init();
  MX_ADC1_Init();
  MX_TIM3_Init();
  MX_USART1_UART_Init();
  /* USER CODE BEGIN 2 */
	HAL_ADC_Start_IT(&hadc1); 
	HAL_TIM_Base_Start(&htim3); 
  /* USER CODE END 2 */

  /* Infinite loop */
  /* USER CODE BEGIN WHILE */
  while (1)
  {
    /* USER CODE END WHILE */

    /* USER CODE BEGIN 3 */
		
	if(adc_convert_cplt == 1)
	{
		memset(txbuf,0,sizeof(txbuf));

		len = sprintf(txbuf,"temperature=%1.2f\n",tc);
		if(len > 0)
			HAL_UART_Transmit_IT(&huart1,(uint8_t*)txbuf,len);
		
		DisplayDigitFLOAT(roundf(tc*100.0f)/100.0f * 100);
		adc_convert_cplt = 0;
	}
  }
  /* USER CODE END 3 */
}

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
/* USER CODE BEGIN 4 */
static float tsp_ResistanceToTemperature( uint16_t adc_val )
{
	float B_value  = TSP_NTC_B_VALUE;
	float Rp_value = TSP_NTC_RATED_RES;
	float T1 = 0.0F;
	float T2 = TSP_NTC_T2_VALUE;
	float Rt_value = 0.0F;
	float volt_val = 0.0F;

	/* Data anomaly judgment */
	if( adc_val <= TSP_SHORT_CIRCUIT_THRESHOLD )
	{
		return 1.0F;
	}
	else if( adc_val >= TSP_OPEN_CIRCUIT_THRESHOLD )
	{
		return 2.0F;
	}
	else
	{
		/* MISRA-C coding rules */
	}

	/* Convert to voltage */
	volt_val = ((float) adc_val * TSP_ADC_VOLTAGE_REF) / TSP_ADC_FULL_SCALE;

	/* Get the NTC resistance value */
	Rt_value = volt_val / ( ( TSP_ADC_VOLTAGE_REF - volt_val ) / TSP_NTC_RATED_RES );
	
	/* Operational formula */
	//T1 = ( 1.0F / ( ( log( Rt_value / Rp_value ) / B_value ) + ( 1.0F / T2 ) ) );

	/* Operational formula */
	T1 = ( 1.0F / ( ( tsp_ln( Rt_value / Rp_value ) / B_value ) + ( 1.0F / T2 ) ) );

	/* Kelvin value convert to degree celsius value */
	T1 = T1 - TSP_NTC_KELVIN_VALUE;

	return ( T1 );
}
/* USER CODE END 4 */
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


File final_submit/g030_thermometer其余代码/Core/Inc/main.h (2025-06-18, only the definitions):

#define LED_A_Pin GPIO_PIN_0
#define LED_A_GPIO_Port GPIOB
#define LED_B_Pin GPIO_PIN_1
#define LED_B_GPIO_Port GPIOB
#define LED_C_Pin GPIO_PIN_2
#define LED_C_GPIO_Port GPIOB
#define LED_CC0_Pin GPIO_PIN_0
#define LED_CC0_GPIO_Port GPIOD
#define LED_CC1_Pin GPIO_PIN_1
#define LED_CC1_GPIO_Port GPIOD
#define LED_CC2_Pin GPIO_PIN_2
#define LED_CC2_GPIO_Port GPIOD
#define LED_CC3_Pin GPIO_PIN_3
#define LED_CC3_GPIO_Port GPIOD
#define LED_D_Pin GPIO_PIN_3
#define LED_D_GPIO_Port GPIOB
#define LED_E_Pin GPIO_PIN_4
#define LED_E_GPIO_Port GPIOB
#define LED_F_Pin GPIO_PIN_5
#define LED_F_GPIO_Port GPIOB
#define LED_G_Pin GPIO_PIN_6
#define LED_G_GPIO_Port GPIOB
#define LED_DP_Pin GPIO_PIN_7
#define LED_DP_GPIO_Port GPIOB

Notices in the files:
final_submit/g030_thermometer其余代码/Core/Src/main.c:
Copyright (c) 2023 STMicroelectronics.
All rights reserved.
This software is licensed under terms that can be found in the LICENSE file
